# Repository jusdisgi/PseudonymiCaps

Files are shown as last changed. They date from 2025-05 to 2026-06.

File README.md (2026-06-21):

# PseudonymiCaps - PG1316 (mostly) Keycaps

Parametric, 3D-printable **keycap profiles** for low-profile mechanical keyboards — sculpted
caps you generate yourself in [OpenSCAD](https://openscad.org/) and export to STL for FDM, resin,
or CNC. Profiles are tuned for **Kailh PG1316S** and **Kailh Choc v1** switches across a range of
key spacings.

> Profiles originate with **Pseudoku** (proprietor of [Asymplex](http://asymplex.xyz/), author of
> the [DES profile](https://kbd.news/On-the-DES-keycap-profile-2229.html)), with additions by
> zzeneg and others. This repo is a slimmed-down, PG1316S-focused descendant — see
> [Why this repo](#why-this-repo).

---

## Quick start (5 minutes)

1. **Install OpenSCAD** (free, all platforms): <https://openscad.org/downloads.html>.
2. **Clone this repo** (the `libraries/` folder must sit next to the profile files).
3. **Open a profile** — e.g. `Subliminal_Contradiction_17x17.scad` — in OpenSCAD.
4. **Pick a key** near the top of the file:
   ```
   keyID = 0;   // which row/size to generate (the comment lists them)
   ```
5. Press **F5** to preview, **F6** to render, then **File → Export → Export as STL**.

That's it. Each profile file has a short **USER KNOBS** block at the top — spacing, stem type, and
which key to render — and you don't need to touch anything below it.

---

## Which file do I open?

| You want… | Open |
|---|---|
| **Subliminal Contradiction** (newest, low + sculpted), alphas | `Subliminal_Contradiction_<spacing>.scad` |
| Subliminal Contradiction thumb / mod caps (convex) | `Subliminal_Contradiction_Convex.scad` |
| **DES** (high-sculpt smooth) | `PG1316_DES_<spacing>_<variant>.scad` |
| **Chicago Stenographer** (subtle low-profile sculpt) | `PG1316_Chicago_Steno_<spacing>_<variant>.scad` |
| Convex / thumb variants of CS | `PG1316_Chicago_Steno_Convex_<spacing>_<variant>.scad` |

`<spacing>` is the key pitch: `17x17`, `18x17`, `19x19`, etc. `<variant>` is the PG1316 mount cutout:
`minZ` (lowest, no foam), `Foam05` (0.5 mm deeper for thin damping foam), or `Foam1` (1 mm deeper).
Subliminal Contradiction also ships a fully parametric master (`Subliminal_Contradiction.scad`)
where you set `unit_x`/`unit_y` yourself, plus standalone presets for **16×16, 17×17, 18×17, and
19.05×19.05**.

### Picking a spacing and stem

- **Stem / switch:** PG1316S caps also fit **Choc v1**. In the Subliminal Contradiction files set
  `stemType` in the USER KNOBS block to `"PG1316S"`, `"Choc"`, or `"MX"`.
- **Spacing:** most low-profile splits use **17×17** or **18×17**. **16×16** is tight/minimal,
  **19.05×19.05** is standard MX spacing. Cap footprint = `pitch − gap` (gap ≈ 1.6 mm by default).

---

## Subliminal Contradiction

A reconstruction of Pseudoku's **Subliminal Contradiction** — a next-gen DES that's lower and
flatter (like Chicago Steno) but as sculpted as DES, with a deeper "huggier" dish and a wide top
surface. The original ships as MX-stem STLs only; here it's rebuilt parametrically so it can be
generated for Choc / PG1316S at low profile and any spacing.

- **Alphas:** 3-row sculpt — `keyID` `1`=R2 (top, leans back), `0`=R3 (home), `2`=R4 (bottom,
  leans forward), `3`=uniform/flat, plus left-hand reach variants (`4`/`5`/`6`). Homing key =
  render `keyID 0` with `homeDot=true`. Right-hand reach = negate the row's `YSkew` (or mirror).
- **Thumbs / mods:** `Subliminal_Contradiction_Convex.scad`, sizes 1.0–2.25u + a slanted thumb.
- **Mount / foam:** every SC file takes a `pgCutout` knob — `"nofoam"` (min height), `"foam05"`,
  `"foam1"` (quieter, auto +0.5/+1.0 mm height), or `"old"` (Kailh) — using the same
  `PG1316_Negspace` cutouts as the DES/CS files. Labeled `_Foam05`/`_Foam1` presets exist for
  17×17 and 18×17; any other spacing just set the knob.
- See [`docs/SC_RECONSTRUCTION.md`](docs/SC_RECONSTRUCTION.md) for exactly how the shape was
  measured from the originals and fit — and how to verify your renders against them
  (`tools/verify_sc.py`, `tools/render_sc.sh`).

---

## PG1316 mount cutouts

The PG1316 / PG1316S switch needs an unusual internal cutout. The DES and Chicago Steno files come
in variants for four cutout shapes (the library shapes live in `libraries/`):

1. **old** — the official Kailh cutout. Works great with the switches, but hard to print accurately.
2. **nofoam** — an "EZ-Print" cutout (by Mike Holscher) designed to 3D-print more easily.
3. **Foam05** — the EZ-Print cutout, 0.5 mm deeper, leaving room for a thin sound-damping foam
   layer (caps are 0.5 mm taller to suit).
4. **Foam1** — EZ-Print, 1 mm deeper, for a thicker foam layer (more cap height again).

---

## Editing profiles / making your own

Every profile is a table of per-key rows. The big `keyParameters` and `dishParameters` arrays
define the cap body and the dish (scoop) respectively. A friendly column-by-column guide lives in
[`docs/PROFILE_PARAMETERS.md`](docs/PROFILE_PARAMETERS.md). Short version: change a number, press
F5, look at the cross-section (`crossSection=true` cuts the cap in half so you can see the walls).

The profile families, briefly:

- **DES (Distorted Ellipsoidal Saddle)** — high-sculpt, smooth row-to-row transition.
- **Chicago Stenographer (CS)** — subtly sculpted, choc-spaced, low profile; convex variant for thumbs.
- **Subliminal Contradiction** — lower/flatter than DES with a deeper dish and broad top (see above).
- **Philadelphia Minimalist** — minimal spacing (upstream, under construction).

---

## Why this repo

Pseudoku's [original repo](https://github.com/pseudoku/PseudoMakeMeKeyCapProfiles) has a long fork
history and a `.git` directory over 1.5 GB (mostly old STL exports). This is a clean, small
descendant — only the files needed to *generate* caps — focused on adapting the profiles to the
ultra-low-profile **Kailh PG1316S** switch (the 17×17 files also fit Choc; PG caps are ~0.5 mm
taller than zzeneg's ultra-low Choc DES because the PG mounting slot needs the room). STL exports
live elsewhere and are linked when available.

## License

See [LICENSE](LICENSE). Profiles derive from Pseudoku's work; please keep attribution.

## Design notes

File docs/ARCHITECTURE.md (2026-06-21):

# Repo architecture & cleanup notes

## How a profile file is organized

Each profile `.scad` has the same shape, top to bottom:

1. `use <./libraries/...>` — the sweep/skin/scad-utils helpers and `PG1316S_Negative_Space.scad`.
2. **USER KNOBS** — `keyID`, spacing (`unit_x`/`unit_y`/`gap`), `stemType`, and the `keycap(...)`
   render call with toggles. *This is the only block most users touch.*
3. **Engine parameters** — resolution + wall/stem constants.
4. **`keyParameters` / `dishParameters`** tables — one row per key (see `PROFILE_PARAMETERS.md`).
5. **Accessor functions** — name the columns (`BottomWidth`, `KeyHeight`, `XAngleSkew`, …).
   In the Subliminal Contradiction files `BottomWidth`/`BottomLength` are spacing-aware
   (`unit_x * units - gap`), so one file works at any pitch.
6. **`keycap` module** + helpers (`choc_stem`, `mx_stem`, `elliptical_rectangle`, …).

Per the repo convention, **one file per spacing** (`*_17x17`, `*_18x17`, `*_19x19`). This avoids
OpenSCAD's `use`-scope limitation: a `use`d module resolves globals like `keyParameters` at the call
site, so cap dimensions can't be cleanly overridden across files. Subliminal Contradiction keeps the
convention with standalone presets, but is *also* parametric (set `unit_x`/`unit_y` in the master).

## Current cleanup done

- Beginner `README.md` with a 5-minute quickstart and a "which file do I open" table.
- `docs/PROFILE_PARAMETERS.md` — plain-language column reference.
- `docs/SC_RECONSTRUCTION.md` — worked example (measure a target, fit parameters).
- Consistent **USER KNOBS** header + `stemType` selector across the new Subliminal Contradiction
  files, which serve as the clean exemplar for the house style.
- `tools/` — STL slicer, the numpy port of the shell math, and a render+overlay verifier.

## Proposed deeper refactor (render-gated)

The `keycap` module and pure helper functions are duplicated across ~16 files. The safe way to
de-duplicate, **verified one file at a time in OpenSCAD** (don't do it blind):

1. Move the **pure helpers** (`elliptical_rectangle`, `rounded_rectangle_profile`, `ellipse`,
   `sign_x/sign_y`) into `libraries/keycap_helpers.scad` and `use` them. These have no dependency on
   `keyParameters`, so `use` is safe. Removes the largest block of duplication with low risk.
2. Refactor the `keycap` module to take the parameter **row as an argument** instead of reading the
   global `keyParameters[keyID]`. That makes the whole engine `use`-safe and lets it live in one
   `libraries/keycap_engine.scad`, with each profile reduced to its tables + a thin call.
3. Standardize file/column naming and add the USER KNOBS header to the older DES/CS files.

Step 1 is mechanical and low-risk; steps 2–3 change the module signature and every call site, so
each converted profile should be rendered and (ideally) overlaid against a known-good STL with
`tools/verify_sc.py` before committing.

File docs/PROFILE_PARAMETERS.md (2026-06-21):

# Profile parameters — a friendly guide

Every profile file is driven by two tables: **`keyParameters`** (the cap body) and
**`dishParameters`** (the scooped top). One row per key; `keyID` selects the row. You tune a cap by
editing numbers in these rows and pressing **F5**. Turn on `crossSection=true` to slice the cap in
half and watch the walls and dish as you tweak.

Units are millimetres and degrees. Angles accumulate over the vertical sweep, so a few degrees goes
a long way.

## `keyParameters` columns

| # | Name | What it does |
|--:|---|---|
| 0 | `BotWid` / units | Cap bottom width. In Subliminal Contradiction this column is **width in units** and the footprint is computed as `unit_x * units - gap`. In the older files it's an absolute mm width. |
| 1 | `BotLen` / units | Cap bottom length (same convention as col 0, using `unit_y`). |
| 2 | `TWDif` | How much **narrower the top is than the bottom**, in width. Bigger = more taper / smaller top. Smaller = wider top surface. |
| 3 | `TLDif` | Same, for length (front-to-back). |
| 4 | `keyh` | **Cap height** (top above the seating plane). The single biggest knob for profile height. |
| 5 | `WSft` | Shifts the top sideways (X) relative to the bottom. |
| 6 | `LSft` | Shifts the top forward/back (Y). |
| 7 | `XSkew` | **Front-back tilt.** Negative leans the cap **back** (top rows), positive leans it **forward** (bottom rows). |
| 8 | `YSkew` | **Left-right tilt.** Used for inner-column "reach" keys; positive raises the right edge. |
| 9 | `ZSkew` | Yaw (rotation about vertical). Usually 0. |
| 10 | `WEx` | Width taper *exponent* — how the taper is distributed up the height (2 ≈ gentle barrel). |
| 11 | `LEx` | Length taper exponent. |
| 12 | `CapR0i` | Corner rounding at the **bottom**, axis 0. |
| 13 | `CapR0f` | Corner rounding at the **top**, axis 0. Larger = rounder top corners. |
| 14 | `CapR1i` | Corner rounding at the bottom, axis 1. |
| 15 | `CapR1f` | Corner rounding at the top, axis 1. |
| 16 | `CapREx` | Exponent controlling how rounding blends bottom→top. |
| 17 | `StemEx` | Exponent for the stem-to-top transition support. |

## `dishParameters` columns

The dish is a saddle swept from a **front** trajectory and a **back** trajectory that meet in the
middle. Most rows only need small tweaks from a working baseline.

| # | Name | What it does |
|--:|---|---|
| 0 | `FFwd1` | Front trajectory: first segment length. |
| 1 | `FFwd2` | Front trajectory: second segment length. |
| 2 | `FPit1` | Front pitch (curvature) of segment 1 — controls how the front lip rises. |
| 3 | `FPit2` | Front pitch of segment 2. |
| 4 | `DshDep` | **Dish depth** — how deep the scoop is. Bigger = "huggier". |
| 5 | `DshHDif` | How far **below the cap top** the dish sits (vertical placement of the scoop). |
| 6 | `FArcIn` | Front dish arc radius at the start (side-to-side curvature of the scoop). |
| 7 | `FArcFn` | Front dish arc radius at the end. |
| 8 | `FArcEx` | Exponent blending `FArcIn`→`FArcFn`. |
| 9–15 | `BFwd1 BFwd2 BPit1 BPit2 BArcIn BArcFn BArcEx` | Same set for the **back** half of the saddle. |

## Common edits

- **Lower the whole cap:** decrease `keyh` (col 4), or set the file's global `heightDelta` negative.
- **Wider, flatter top (more keycap surface):** decrease `TWDif`/`TLDif`.
- **Deeper scoop:** increase `DshDep`; if it pokes through the wall, also nudge `DshHDif`.
- **Change row tilt:** adjust `XSkew` (front-back). Negative = leans back, positive = leans forward.
- **Inner-column reach key:** add a few degrees of `YSkew` (negate for the opposite hand).
- **Inspect walls/dish:** set `crossSection=true` in the render call and press F5.

See [`SC_RECONSTRUCTION.md`](SC_RECONSTRUCTION.md) for a worked example: measuring a target shape
and fitting these parameters to it.

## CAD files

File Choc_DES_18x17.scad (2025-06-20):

use <./libraries/scad-utils/morphology.scad> //for cheaper minwoski
use <./libraries/scad-utils/transformations.scad>
use <./libraries/scad-utils/shapes.scad>
use <./libraries/scad-utils/trajectory.scad>
use <./libraries/scad-utils/trajectory_path.scad>
use <./libraries/sweep.scad>
use <./libraries/skin.scad>
//use <z-butt.scad>

/*DES (Distorted Elliptical Saddle) Sculpted Profile for 6x3 and corne thumb
Version 2: Eliptical Rectangle
*/

//Cheat Sheet: key KeyIDs to know
//0 Regular bottom alpha row (R4)
//1 Regular home row (R3)
//2 Regular top alpha row (R2)
//5 Regular num row (R1)
//43 Edge R4
//44 Edge R3
//45 Edge R2
//46 Edge R1
//47 Thumb
//48 Thumb
//49 Thumb

// Configure keycap to render here. You probably only want to
// do one at a time unless your computer is real fast.
keycap(
    keyID  = 1, //change profile refer to KeyParameters Struct
    Stem   = true, //tusn on shell and stems
    Dish   = true, //turn on dish cut
    visualizeDish = false, // turn on debug visual of Dish
    crossSection  = false, // center cut to check internal
    homeDot = false, //turn on homedots
    homeRing = false, //turn on homing rings
    homeBar = true, //turn on homing bar
    Legends = false
);


//Cheat Sheet: key KeyIDs to know
//0 Regular bottom alpha row (R4)
//1 Regular home row (R3)
//2 Regular top alpha row (R2)
//5 Regular num row (R1)
//43 Edge R4
//44 Edge R3
//45 Edge R2
//46 Edge R1
//47 Thumb
//48 Thumb
//49 Thumb

//Parameters
wallthickness = 1.2; // 1.5 for norm, 1.2 for cast master
topthickness  = 1.2; // 2 for norm, 1.6 for cast master
stepsize      = 60;  //resolution of Trajectory
step          = 0.5;   //resolution of ellipes
fn            = 60;  //resolution of Rounded Rectangles: 60 for output
layers        = 50;  //resolution of vertical Sweep: 50 for output
dotRadius     = 0.55;   //home dot size; default 0.55
//---Stem param
stemLayers      = 50; //resolution of stem to cap top transition
stemHeightDelta = 0.3;

heightDelta = -5.25;

keyParameters = //keyParameters[KeyID][ParameterID]
[
//  BotWid, BotLen, TWDif, TLDif, keyh, WSft, LSft  XSkew, YSkew, ZSkew, WEx, LEx, CapR0i, CapR0f, CapR1i, CapR1f, CapREx, StemEx
//Column high sculpt 3 row system
    //0~5
    [16.4,  15.4,   6.5, 	 4.5,10.55,    0,    0,     9,     0,     0,   2,   2,      1,      5,      1,    3.5,     2,       2], //0 R4 8
    [16.4,  15.4,   6.5, 	 4.5, 8.75,    0,   .5,     4,     0,     0,   2,   2,      1,      5,      1,    3.5,     2,       2], //1 R3 Home
    [16.4,  15.4,   6.5, 	 4.5, 9.75,    0,    0,   -13,     0,     0,   2,   2,      1,      5,      1,    3.5,     2,       2], //2 R2
    [16.4,  15.4,   6.5, 	 4.5, 8.75,    0,    0,     4,     0,     0,   2,   2,      1,      5,      1,    3.5,     2,       2], //3 R3 deepdish
    [16.4,  15.4,   6.5, 	 4.5, 11.5,    0,    0,    -3,     0,     0,   2,   2,      1,      5,      1,    3.5,     2,       2], //4 R5 mod
    [16.4,  15.4,   6.5, 	 4.5, 15.0,    0,  -.5,    20,     0,     0,   2,   2,      1,      5,      1,    3.5,     2,       2], //5 R1 num

    //1.25u 6~9
    [20.6,  15.4,   6.5, 	 4.5, 11.5,    0,    0,    -3,     0,     0,   2,   2,      1,      5,      1,    3.5,     2,       2], //6 R5
    [20.6,  15.4,   6.5, 	 4.5,10.55,    0,    0,     9,     0,     0,   2,   2,      1,      5,      1,    3.5,     2,       2], //7 R4  // neuron 3 deg
    [20.6,  15.4,   6.5, 	 4.5, 8.75,    0,   .5,     4,    -0,     0,   2,   2,      1,      5,      1,    3.5,     2,       2], //8 R3 Home
    [20.6,  15.4,   6.5, 	 4.5, 9.75,    0,    0,   -13,     0,     0,   2,   2,      1,      5,      1,    3.5,     2,       2], //9 R2
    //1.5u 10~13
    [2,  15.4,   6.5, 	 4.5, 11.5,    0,    0,    -3,     0,     0,   2,   2,      1,      5,      1,    3.5,     2,       2], //10 R5
    [24.9,  15.4,   6.5, 	 4.5,10.55,    0,    0,     9,     0,     0,   2,   2,      1,      5,      1,    3.5,     2,       2], //11 R4
    [24.9,  15.4,   6.5, 	 4.5, 8.75,    0,   .5,     4,     0,     0,   2,   2,      1,      5,      1,    3.5,     2,       2], //12 R3 Home
    [24.9,  15.4,   6.5, 	 4.5, 9.75,    0,    0,   -13,     0,     0,   2,   2,      1,      5,      1,    3.5,     2,       2], //13 R2
    //1.75u 14~17
    [29.2,  15.4,   6.5, 	 4.5, 11.5,    0,    0,    -3,     0,     0,   2,   2,      1,      5,      1,    3.5,     2,       2], //14 R5
    [29.2,  15.4,   6.5, 	 4.5,10.55,    0,    0,     9,    -0,     0,   2,   2,      1,      5,      1,    3.5,     2,       2], //15 R4
    [29.2,  15.4,   6.5, 	 4.5, 8.75,    0,   .5,     4,     0,     0,   2,   2,      1,      5,      1,    3.5,     2,       2], //16 R3 Home
    [29.2,  15.4,   6.5, 	 4.5, 9.75,    0,    0,   -13,     0,     0,   2,   2,      1,      5,      1,    3.5,     2,       2], //17 R2
    //2.0u  18~22
    [33.4,  15.4,   6.5, 	 4.5, 11.5,    0,    0,    -3,     0,     0,   2,   2,      1,      5,      1,    3.5,     2,       2], //18 R5
    [33.4,  15.4,   6.5, 	 4.5,10.55,    0,    0,     9,     0,     0,   2,   2,      1,      5,      1,    3.5,     2,       2], //19 R4
    [33.4,  15.4,   6.5, 	 4.5, 8.75,    0,   .5,     4,     0,     0,   2,   2,      1,      5,      1,    3.5,     2,       2], //20 R3 Home
    [33.4,  15.4,   6.5, 	 4.5, 9.75,    0,    0,   -13,     0,     0,   2,   2,      1,      5,      1,    3.5,     2,       2], //21 R2
    [33.4,  15.4,   6.5, 	 4.5,   15,    0,  -.5,    20,     0,     0,   2,   2,      1,      5,      1,    3.5,     2,       2], //22 R1
    //2.25u 23~26
    [37.7,  15.4,   6.5, 	 4.5, 11.5,    0,    0,    -3,    -0,     0,   2,   2,      1,      5,      1,    3.5,     2,       2], //23 R5
    [37.7,  15.4,   6.5, 	 4.5,10.55,    0,    0,     9,     0,     0,   2,   2,      1,      5,      1,    3.5,     2,       2], //24 R4
    [37.7,  15.4,   6.5, 	 4.5, 8.75,    0,   .5,     4,     0,     0,   2,   2,      1,      5,      1,    3.5,     2,       2], //25 R3 Home
    [37.7,  15.4,   6.5, 	 4.5, 9.75,    0,    0,   -13,     0,     0,   2,   2,      1,      5,      1,    3.5,     2,       2], //26 R2
    //2.50u 27~30
    [41.9,  15.4,   6.5, 	 4.5, 11.5,    0,    0,    -3,     0,     0,   2,   2,      1,      5,      1,    3.5,     2,       2], //27 R5  // neuron 2deg height to 10.5
    [41.9,  15.4,   6.5, 	 4.5,10.55,    0,    0,     9,     0,     0,   2,   2,      1,      5,      1,    3.5,     2,       2], //28 R4
    [41.9,  15.4,   6.5, 	 4.5, 8.75,    0,   .5,     4,     0,     0,   2,   2,      1,      5,      1,    3.5,     2,       2], //29 R3 Home
    [41.9,  15.4,   6.5, 	 4.5, 9.75,    0,    0,   -13,     0,     0,   2,   2,      1,      5,      1,    3.5,     2,       2], //30 R2
    //2.75u 31~34
    [46.2,  15.4,   6.5, 	 4.5, 11.5,    0,    0,    -3,     0,     0,   2,   2,      1,      5,      1,    3.5,     2,       2], //31 R5
    [46.2,  15.4,   6.5, 	 4.5,10.55,    0,    0,     9,     0,     0,   2,   2,      1,      5,      1,    3.5,     2,       2], //32 R4
    [46.2,  15.4,   6.5, 	 4.5, 8.75,    0,   .5,    -4,     0,     0,   2,   2,      1,      5,      1,    3.5,     2,       2], //33 R3 Home
    [46.2,  15.4,   6.5, 	 4.5, 9.75,    0,    0,   -13,     0,     0,   2,   2,      1,      5,      1,    3.5,     2,       2], //34 R2
    //3.00u 34~37
    [50.4,  15.4,   6.5, 	 4.5, 11.5,    0,    0,    -3,    -0,     0,   2,   2,      1,      5,      1,    3.5,     2,       2], //35 R5
    [50.4,  15.4,   6.5, 	 4.5,10.55,    0,    0,     9,     0,     0,   2,   2,      1,      5,      1,    3.5,     2,       2], //36 R4
    [50.4,  15.4,   6.5, 	 4.5, 8.75,    0,   .5,     4,     0,     0,   2,   2,      1,      5,      1,    3.5,     2,       2], //37 R3 Home
    [50.4,  15.4,   6.5, 	 4.5, 9.75,    0,    0,   -13,     0,     0,   2,   2,      1,      5,      1,    3.5,     2,       2], //38 R2
    //6.25u 39
    [105.7,  15.4,   6.5, 	 4.5, 11.5,    0,    0,    -3,    -0,     0,   2,   2,      1,      5,      1,    3.5,     2,       2], //39 R5
    //7.00u 40
    [118.4,  15.4,   6.5, 	 4.5, 11.5,    0,    0,    -3,    -0,     0,   2,   2,      1,      5,      1,    3.5,     2,       2], //40 R5
    //num pad vert  2u 41
    [16.4,  33.4,   6.5, 	 6.5,10.00,    0,    0,    -5,     0,     0,   2,   2,      1,      6,      1,    3.5,     2,       2], //41 R4
    [16.4,  33.4,   6.5, 	 6.5,10.55,    0,    0,     9,     0,     0,   2,   2,      1,      5,      1,    3.5,     2,       2], //42 R4
    //edge 43-46
    [16.4,  15.4,   6.5, 	 4.5, 11.8,    0,    0,     9,    15,     0,   2,   2,      1,      5,      1,    3.5,     2,       2], //43 R4
    [16.4,  15.4,   6.5, 	 4.5,   10,    0,   .5,     4,    15,     0,   2,   2,      1,      5,      1,    3.5,     2,       2], //44 R3
    [16.4,  15.4,   6.5, 	 4.5,   11,    0,    0,   -13,    15,     0,   2,   2,      1,      5,      1,    3.5,     2,       2], //45 R2
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

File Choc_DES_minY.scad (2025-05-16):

use <./libraries/scad-utils/morphology.scad> //for cheaper minwoski
use <./libraries/scad-utils/transformations.scad>
use <./libraries/scad-utils/shapes.scad>
use <./libraries/scad-utils/trajectory.scad>
use <./libraries/scad-utils/trajectory_path.scad>
use <./libraries/sweep.scad>
use <./libraries/skin.scad>
//use <z-butt.scad>

/*DES (Distorted Elliptical Saddle) Sculpted Profile for 6x3 and corne thumb
Version 2: Eliptical Rectangle
*/

//Cheat Sheet: key KeyIDs to know
//0 Regular bottom alpha row (R4)
//1 Regular home row (R3)
//2 Regular top alpha row (R2)
//5 Regular num row (R1)
//43 Edge R4
//44 Edge R3
//45 Edge R2
//46 Edge R1
//47 Thumb
//48 Thumb
//49 Thumb

// Configure keycap to render here. You probably only want to
// do one at a time unless your computer is real fast.
keycap(
    keyID  = 1, //change profile refer to KeyParameters Struct
    Stem   = true, //tusn on shell and stems
    Dish   = true, //turn on dish cut
    visualizeDish = false, // turn on debug visual of Dish
    crossSection  = false, // center cut to check internal
    homeDot = false, //turn on homedots
    homeRing = false, //turn on homing rings
    Legends = false
);

//Parameters
wallthickness = 1.2; // 1.5 for norm, 1.2 for cast master
topthickness  = 1.2; // 2 for norm, 1.6 for cast master
stepsize      = 60;  //resolution of Trajectory
step          = 0.5;   //resolution of ellipes
fn            = 60;  //resolution of Rounded Rectangles: 60 for output
layers        = 50;  //resolution of vertical Sweep: 50 for output
dotRadius     = 0.55;   //home dot size; default 0.55
//---Stem param
stemLayers      = 50; //resolution of stem to cap top transition
stemHeightDelta = 0.3;

heightDelta = -5.25;

keyParameters = //keyParameters[KeyID][ParameterID]
[
//  BotWid, BotLen, TWDif, TLDif, keyh, WSft, LSft  XSkew, YSkew, ZSkew, WEx, LEx, CapR0i, CapR0f, CapR1i, CapR1f, CapREx, StemEx
//Column high sculpt 3 row system
    //0~5
    [17.16,  14.36,   6.5, 	 4.5,10.55,    0,    0,     9,     0,     0,   2,   2,      1,      5,      1,    3.5,     2,       2], //0 R4 8
    [17.16,  14.36,   6.5, 	 4.5, 8.75,    0,   .5,     4,     0,     0,   2,   2,      1,      5,      1,    3.5,     2,       2], //1 R3 Home
    [17.16,  14.36,   6.5, 	 4.5, 9.75,    0,    0,   -13,     0,     0,   2,   2,      1,      5,      1,    3.5,     2,       2], //2 R2
    [17.16,  14.36,   6.5, 	 4.5, 8.75,    0,    0,     4,     0,     0,   2,   2,      1,      5,      1,    3.5,     2,       2], //3 R3 deepdish
    [17.16,  14.36,   6.5, 	 4.5, 11.5,    0,    0,    -3,     0,     0,   2,   2,      1,      5,      1,    3.5,     2,       2], //4 R5 mod
    [17.16,  14.36,   6.5, 	 4.5, 15.0,    0,  -.5,    20,     0,     0,   2,   2,      1,      5,      1,    3.5,     2,       2], //5 R1 num

    //1.25u 6~9
    [21.86,  14.36,   6.5, 	 4.5, 11.5,    0,    0,    -3,     0,     0,   2,   2,      1,      5,      1,    3.5,     2,       2], //6 R5
    [21.86,  14.36,   6.5, 	 4.5,10.55,    0,    0,     9,     0,     0,   2,   2,      1,      5,      1,    3.5,     2,       2], //7 R4  // neuron 3 deg
    [21.86,  14.36,   6.5, 	 4.5, 8.75,    0,   .5,     4,    -0,     0,   2,   2,      1,      5,      1,    3.5,     2,       2], //8 R3 Home
    [21.86,  14.36,   6.5, 	 4.5, 9.75,    0,    0,   -13,     0,     0,   2,   2,      1,      5,      1,    3.5,     2,       2], //9 R2
    //1.5u 10~13
    [26.66,  14.36,   6.5, 	 4.5, 11.5,    0,    0,    -3,     0,     0,   2,   2,      1,      5,      1,    3.5,     2,       2], //10 R5
    [26.66,  14.36,   6.5, 	 4.5,10.55,    0,    0,     9,     0,     0,   2,   2,      1,      5,      1,    3.5,     2,       2], //11 R4
    [26.66,  14.36,   6.5, 	 4.5, 8.75,    0,   .5,     4,     0,     0,   2,   2,      1,      5,      1,    3.5,     2,       2], //12 R3 Home
    [26.66,  14.36,   6.5, 	 4.5, 9.75,    0,    0,   -13,     0,     0,   2,   2,      1,      5,      1,    3.5,     2,       2], //13 R2
    //1.75u 14~17
    [31.40,  14.36,   6.5, 	 4.5, 11.5,    0,    0,    -3,     0,     0,   2,   2,      1,      5,      1,    3.5,     2,       2], //14 R5
    [31.40,  14.36,   6.5, 	 4.5,10.55,    0,    0,     9,    -0,     0,   2,   2,      1,      5,      1,    3.5,     2,       2], //15 R4
    [31.40,  14.36,   6.5, 	 4.5, 8.75,    0,   .5,     4,     0,     0,   2,   2,      1,      5,      1,    3.5,     2,       2], //16 R3 Home
    [31.40,  14.36,   6.5, 	 4.5, 9.75,    0,    0,   -13,     0,     0,   2,   2,      1,      5,      1,    3.5,     2,       2], //17 R2
    //2.0u  18~22
    [36.26,  14.36,   6.5, 	 4.5, 11.5,    0,    0,    -3,     0,     0,   2,   2,      1,      5,      1,    3.5,     2,       2], //18 R5
    [36.26,  14.36,   6.5, 	 4.5,10.55,    0,    0,     9,     0,     0,   2,   2,      1,      5,      1,    3.5,     2,       2], //19 R4
    [36.26,  14.36,   6.5, 	 4.5, 8.75,    0,   .5,     4,     0,     0,   2,   2,      1,      5,      1,    3.5,     2,       2], //20 R3 Home
    [36.26,  14.36,   6.5, 	 4.5, 9.75,    0,    0,   -13,     0,     0,   2,   2,      1,      5,      1,    3.5,     2,       2], //21 R2
    [36.26,  14.36,   6.5, 	 4.5,   15,    0,  -.5,    20,     0,     0,   2,   2,      1,      5,      1,    3.5,     2,       2], //22 R1
    //2.25u 23~26
    [40.96,  14.36,   6.5, 	 4.5, 11.5,    0,    0,    -3,    -0,     0,   2,   2,      1,      5,      1,    3.5,     2,       2], //23 R5
    [40.96,  14.36,   6.5, 	 4.5,10.55,    0,    0,     9,     0,     0,   2,   2,      1,      5,      1,    3.5,     2,       2], //24 R4
    [40.96,  14.36,   6.5, 	 4.5, 8.75,    0,   .5,     4,     0,     0,   2,   2,      1,      5,      1,    3.5,     2,       2], //25 R3 Home
    [40.96,  14.36,   6.5, 	 4.5, 9.75,    0,    0,   -13,     0,     0,   2,   2,      1,      5,      1,    3.5,     2,       2], //26 R2
    //2.50u 27~30
    [45.66,  14.36,   6.5, 	 4.5, 11.5,    0,    0,    -3,     0,     0,   2,   2,      1,      5,      1,    3.5,     2,       2], //27 R5  // neuron 2deg height to 10.5
    [45.66,  14.36,   6.5, 	 4.5,10.55,    0,    0,     9,     0,     0,   2,   2,      1,      5,      1,    3.5,     2,       2], //28 R4
    [45.66,  14.36,   6.5, 	 4.5, 8.75,    0,   .5,     4,     0,     0,   2,   2,      1,      5,      1,    3.5,     2,       2], //29 R3 Home
    [45.66,  14.36,   6.5, 	 4.5, 9.75,    0,    0,   -13,     0,     0,   2,   2,      1,      5,      1,    3.5,     2,       2], //30 R2
    //2.75u 31~34
    [50.66,  14.36,   6.5, 	 4.5, 11.5,    0,    0,    -3,     0,     0,   2,   2,      1,      5,      1,    3.5,     2,       2], //31 R5
    [50.66,  14.36,   6.5, 	 4.5,10.55,    0,    0,     9,     0,     0,   2,   2,      1,      5,      1,    3.5,     2,       2], //32 R4
    [50.66,  14.36,   6.5, 	 4.5, 8.75,    0,   .5,    -4,     0,     0,   2,   2,      1,      5,      1,    3.5,     2,       2], //33 R3 Home
    [50.66,  14.36,   6.5, 	 4.5, 9.75,    0,    0,   -13,     0,     0,   2,   2,      1,      5,      1,    3.5,     2,       2], //34 R2
    //3.00u 34~37
    [55.36,  14.36,   6.5, 	 4.5, 11.5,    0,    0,    -3,    -0,     0,   2,   2,      1,      5,      1,    3.5,     2,       2], //35 R5
    [55.36,  14.36,   6.5, 	 4.5,10.55,    0,    0,     9,     0,     0,   2,   2,      1,      5,      1,    3.5,     2,       2], //36 R4
    [55.36,  14.36,   6.5, 	 4.5, 8.75,    0,   .5,     4,     0,     0,   2,   2,      1,      5,      1,    3.5,     2,       2], //37 R3 Home
    [55.36,  14.36,   6.5, 	 4.5, 9.75,    0,    0,   -13,     0,     0,   2,   2,      1,      5,      1,    3.5,     2,       2], //38 R2
    //6.25u 39
    [117.1,  14.36,   6.5, 	 4.5, 11.5,    0,    0,    -3,    -0,     0,   2,   2,      1,      5,      1,    3.5,     2,       2], //39 R5
    //7.00u 40
    [131.4,  14.36,   6.5, 	 4.5, 11.5,    0,    0,    -3,    -0,     0,   2,   2,      1,      5,      1,    3.5,     2,       2], //40 R5
    //num pad vert  2u 41
    [17.16,  36.26,   6.5, 	 6.5,10.00,    0,    0,    -5,     0,     0,   2,   2,      1,      6,      1,    3.5,     2,       2], //41 R4
    [17.16,  36.26,   6.5, 	 6.5,10.55,    0,    0,     9,     0,     0,   2,   2,      1,      5,      1,    3.5,     2,       2], //42 R4
    //edge 43-46
    [17.16,  14.36,   6.5, 	 4.5, 11.8,    0,    0,     9,    15,     0,   2,   2,      1,      5,      1,    3.5,     2,       2], //43 R4
    [17.16,  14.36,   6.5, 	 4.5,   10,    0,   .5,     4,    15,     0,   2,   2,      1,      5,      1,    3.5,     2,       2], //44 R3
    [17.16,  14.36,   6.5, 	 4.5,   11,    0,    0,   -13,    15,     0,   2,   2,      1,      5,      1,    3.5,     2,       2], //45 R2
    [17.16,  14.36,   6.5, 	 4.5, 15.3,    0,  -.5,   -20,    15,     0,   2,   2,      1,      5,      1,    3.5,     2,       2], //46 R1 num
    //thumbs 47-49
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

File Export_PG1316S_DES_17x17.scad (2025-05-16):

use <PG1316S_DES_17x17.scad>

spacing = 17.00;
vertical_spacing = 17.00;
spru_radius = 0.8;
width=1;

spru_n = 3;
start_row = 2; end_row = 4;

union() {
    for (i = [start_row : end_row]) {
        translate([0, -vertical_spacing * (i - start_row), 0]) des_spru(row=i, width=width, dot=false, edge=false);

        if (i != end_row) {
            translate([5, -vertical_spacing * (i - start_row) - 5, -0.8 * spru_radius])
            rotate([90, 0, 0])
            cylinder(h = 6, r = spru_radius, $fn=20);
        }
    }
}

//union() {
//    translate([0, -19 *  0, 0])  des_spru(row=1);
//    translate([0, -19 *  1, 0])  des_spru(row=2);
//    translate([0, -19 *  2, 0])  des_spru(row=3);
//    translate([0, -19 *  3, 0])  des_spru(row=4);
//    translate([0, -19 *  4, 0])  des_spru(row=5);
//
//    translate([0, -19 *  6, 0])  des_spru(row=2, width=1.25);
//  translate([0, -19 *  7, 0])  des_spru(row=3, width=1.25);
//  translate([0, -19 *  8, 0])  des_spru(row=4, width=1.25);
//  translate([0, -19 *  9, 0])  des_spru(row=5, width=1.25);
//
//  translate([0, -19 * 11, 0])  des_spru(row=2, width=1.5);
//  translate([0, -19 * 12, 0])  des_spru(row=3, width=1.5);
//  translate([0, -19 * 13, 0])  des_spru(row=4, width=1.5);
//    translate([0, -19 * 14, 0])  des_spru(row=5, width=1.5);
//
//  translate([0, -19 * 16, 0])  des_spru(row=2, width=1.75);
//  translate([0, -19 * 17, 0])  des_spru(row=3, width=1.75);
//  translate([0, -19 * 18, 0])  des_spru(row=4, width=1.75);
//  translate([0, -19 * 19, 0])  des_spru(row=5, width=1.75);

//  translate([0, -19 * 21, 0])  des_spru(row=5, width=2);
//  translate([0, -19 * 22, 0])  des_spru(row=5, width=2.25);
//  translate([0, -19 * 23, 0])  des_spru(row=5, width=2.75);

//    translate([0, -19 * 25, 0])  des_spru(row=3, dot=true);
//    translate([0, -19 * 0, 0])  des_spru(row=3, ring=true);
//    translate([0, -19 * 26, 0])  des_spru(row=3, deepdish=true);
//    translate([0, -19 * 27, 0])  des_spru(row=3, deepdish=false);
//}

module des_spru(row, dot=false, deepdish=false, n=spru_n, width=1, radius=spru_radius, ring=false, edge=false) {
    echo ("Row", row, "width", width);
    union() {
        for (i = [0 : n - 1]){
            translate([i * spacing * width, 0, 0])
            mirror([0,0,0])
            des_keycap(row=row, width=width, dot=dot, deepdish=deepdish, ring=ring, edge=edge);

            if (edge) {
                translate([(i + 1) * spacing * width, 0, 0])
                mirror([1,0,0])
                des_keycap(row=row, width=width, dot=dot, deepdish=deepdish, ring=ring, edge=edge);
            }
        }

        if (n > 1 || edge) {
            for (i = [0 : max(0, n - 2)]){
                translate([i * width * spacing + spacing / 2 - 3, 5, -0.8 * spru_radius])
                rotate([0, 90, 0])
                cylinder(h = 6, r = spru_radius, $fn=20);
            }
        }
    }
}

module des_keycap(row, width=1, dot=false, deepdish=false, ring=false, edge=false) {
    if      (row == 1 && edge) {des_standard(46);}
    else if (row == 1) {rotate([0, 0, 180]) des_standard(5);}

    else if (row == 2 && edge) {des_standard(45);}
    else if (row == 2 && width == 1   ) {des_standard(2);}
    else if (row == 2 && width == 1.25) {des_standard(9);}
    else if (row == 2 && width == 1.5 ) {des_standard(13);}
    else if (row == 2 && width == 1.75) {des_standard(17);}

    else if (row == 3 && edge) {des_standard(44);}
    else if (row == 3 && width == 1 && !deepdish) {des_standard(1, dot=dot, ring=ring);}
    else if (row == 3 && deepdish)      {des_standard(3);}
    else if (row == 3 && width == 1.25) {des_standard(8);}
    else if (row == 3 && width == 1.5 ) {des_standard(12);}
    else if (row == 3 && width == 1.75) {des_standard(16);}

    else if (row == 4 && edge) {des_standard(43);}
    else if (row == 4 && width == 1   ) {des_standard(0);}
    else if (row == 4 && width == 1.25) {des_standard(7);}
    else if (row == 4 && width == 1.5 ) {des_standard(11);}
    else if (row == 4 && width == 1.75) {des_standard(15);}

    else if (row == 5 && width == 1   ) {des_standard(4);}
    else if (row == 5 && width == 1.25) {des_standard(6);}
    else if (row == 5 && width == 1.5 ) {des_standard(10);}
    else if (row == 5 && width == 1.75) {des_standard(14);}
    else if (row == 5 && width == 2   ) {des_standard(18);}
    else if (row == 5 && width == 2.25) {des_standard(23);}
    else if (row == 5 && width == 2.75) {des_standard(31);}
}

module des_standard(keyID, dot=false, ring=false) {
    echo("keyID", keyID)
    keycap(
        keyID  = keyID, //change profile refer to KeyParameters Struct
        Stem   = false, //turn on shell and stems
        PG1316S = true, //turn on mounting slot
        crossSection = false,
        homeDot = dot, //turn on homedots
        homeRing = ring
    );
}

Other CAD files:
PG1316_Chicago_Steno_17x17_Foam05.scad
PG1316S_Chicago_Steno.scad
PG1316S_Chicago_Steno_17x17.scad
PG1316S_Chicago_Steno_18x17.scad
PG1316S_Chicago_Steno_19x19.scad
PG1316S_Chicago_Steno_Convex.scad
PG1316S_Chicago_Steno_Convex_17x17.scad
PG1316S_Chicago_Steno_Convex_18x17.scad
PG1316S_Chicago_Steno_Convex_19x19.scad
PG1316S_Chicago_Steno_Thumb_18x17.scad
PG1316S_Chicago_Steno_Thumb_19x19.scad
PG1316S_DES_17x17.scad
PG1316S_DES_17x17_Foam05.scad
PG1316S_DES_17x17_Foam1.scad
PG1316S_DES_18x17.scad
PG1316S_DES_18x17_Foam05.scad
PG1316S_DES_18x17_Foam1.scad
PG1316S_DES_19x19.scad
PG1316S_DES_19x19_Foam05.scad
PG1316S_DES_19x19_Foam1.scad
PG1316S_Negative_Space.scad
PG1316_Chicago_Steno_17x17_Foam1.scad
PG1316_Chicago_Steno_17x17_minZ.scad
PG1316_Chicago_Steno_18x17_Foam05.scad
PG1316_Chicago_Steno_18x17_Foam1.scad
PG1316_Chicago_Steno_18x17_minZ.scad
PG1316_Chicago_Steno_19x19_Foam05.scad
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

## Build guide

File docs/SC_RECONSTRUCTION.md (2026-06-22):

# Subliminal Contradiction — reconstruction notes

Pseudoku released **Subliminal Contradiction (SC)** as MX-stem / MX-spaced **STL meshes only**
(no parametric source; "Choc stem variants" is an open to-do in the original repo). To make SC
usable on Choc / Kailh PG1316S boards at low profile, the shape was **reconstructed
parametrically** in this repo's engine rather than mesh-grafted, so the result is a clean,
manifold, fully parametric cap suitable for FDM, resin, and CNC.

This document records how the parameters were derived so the fit is reproducible and tunable.

## Source geometry (measured from the original STLs)

The original STLs were parsed and sliced with `tools/sc_slice.py` (pure-numpy binary-STL reader +
plane sectioner). All caps share an **18.06 × 18.06 mm** 1u footprint (MX), convex sizes grow
4.76 mm/u. The seating plane sits at **z ≈ 0**; the skirt extends to z ≈ −1.0.

Per-row top-surface measurements (z in mm above seating plane; −Y = front):

| Cap | front rim | back rim | front-back tilt | dish min | side rim | side dish depth |
|---|---:|---:|---:|---:|---:|---:|
| R2 (top) | 3.44 | 5.95 |  **+2.51** (back high) | 2.67 | 5.40 | 1.95 |
| R3 (home)| 4.27 | 3.81 |  −0.46 (near flat) | 2.91 | 5.06 | 1.91 |
| R4 (bot) | 5.72 | 4.30 |  **−1.42** (front high) | 3.88 | 6.11 | 1.79 |
| Uniform  | 4.22 | 4.22 | 0.00 (flat) | 3.15 | 5.06 | 1.91 |
| Convex | ~5.3 center (domed) | — | — | — | — | — |
| R2 reach | 3.94 | 6.46 |  +2.52 | 3.19 |  5.11 / 6.33 (L/R) | lateral lean |
| R3 reach | 4.78 | 4.32 |  −0.45 | 3.53 |  4.92 / 5.88 | lateral lean |
| R4 reach | 6.24 | 4.80 |  −1.44 | 4.39 |  6.21 / 6.83 | lateral lean |

This matches the published spec (max height ~6.5 mm, dish minima ~3.2 mm). Key shape signatures:
a 3-row sculpt (R2 leans back, R3 ~flat, R4 leans forward), a **broad top surface** (little
taper), a **side-to-side saddle ~1.9 mm deep**, and "Left Reachy" inner-column variants that add a
**lateral lean** (right rim higher than left) on top of the row tilt.

## Fitting to the engine

Rim heights and tilts are **edge** features, so they're unaffected by the dish cut. The engine's
outer-shell math (`elliptical_rectangle` + `CapTransform/CapTranslation/CapRotation`) was ported to
numpy (`tools/sc_shell_model.py`) to predict front/back/left/right rim heights for a given
parameter row, and `keyh`, `XSkew`, `YSkew` were fit (zero yaw) to the measured rims:

| Row | keyh | XSkew | YSkew | fit RMS (mm) |
|---|-----:|---:|---:|---:|
| R3 home | 4.77 |  +2.1 | 0.0 | 0.51 |
| R2 top | 5.29 | −11.8 | 0.0 | 0.35 |
| R4 bottom  | 5.83 |  +6.7 | 0.0 | 0.55 |
| R3 uniform | 4.86 | 0.0 | 0.0 | 0.42 |
| R2 reach | 5.71 | −11.7 |  +6.9 | 0.27 |
| R3 reach | 5.20 |  +2.5 |  +5.3 | 0.44 |
| R4 reach | 6.30 |  +6.7 |  +3.3 | 0.51 |

Sign convention (confirmed against this engine): **negative XSkew leans the cap back**, positive
leans it forward; positive YSkew raises the right rim (left-hand inner reach).

The residual (~0.3–0.5 mm) is almost entirely SC's **side rims sitting higher** than the DES default
roundness/taper predicts — i.e. SC's "wider top surface area." This is captured by reducing the top
taper (`TWDif 6.5 → 5.5`, `TLDif 4.5 → 4.0`); final side-rim fit is a render-loop tuning step.

## Dish

The saddle dish is **not** fully re-derived analytically (it's a skinned-ellipse sweep). Instead the
known-good **DES dish baseline** is mapped per row (R2/R3/R4), which already lands in SC's measured
dish-minima band (~2.9–3.9 mm). SC's "deeper, huggier dish" is a small `DishDepth`/`DishHeightDif`
increase to verify against the originals — see verification below.

## Minimum height

The PG1316S mount slot (`pg1316s_negspace`) is only **1.5 mm tall** (z 0→1.5), so minimum cap height
is limited by the **dish**, not the mount. SC's native heights (R3 home top 4.27 mm, dish min ~2.9)
already clear the mount with margin, so the reconstruction preserves SC's true low profile. The
global `heightDelta` (0 by default) raises/lowers the whole set if you want to trade dish depth for
even less height.

## Verification (run on a machine with OpenSCAD)

1. `bash tools/render_sc.sh` renders each preset/row to STL via OpenSCAD CLI.
2. `python3 tools/verify_sc.py <rendered.stl> "<original SC STL>"` slices both and overlays
   sagittal + transverse cross-sections, reporting max/RMS deviation of the top surface.
3. The **19.05 MX-stem validation** preset (`Subliminal_Contradiction_19.05_MXstem_validation.scad`,
   gap 0.99 → 18.06 mm footprint) is built specifically to overlay against Pseudoku's original
   STLs and confirm the reconstructed sculpt matches before trusting the Choc/PG variants.

## Tuning log & open issues (status as of last session)

**Workflow reminder:** tune the **master** (`Subliminal_Contradiction.scad`), then run
`python3 tools/make_presets.py` to push the change into every preset (including the validation cap).
Render the **validation cap** (keyID 0) and compare to `STL/1u Row 3.stl` — they share the 18.06 mm
footprint, so the overlay lines up without rescaling. (Gotcha: editing the master alone does nothing
to what you render if you render a preset — always re-run make_presets first.)

**Current tuned parameters** (in the master):
- `heightDelta = 0.5` (rim lift to meet original SC rim height)
- dish `DishDepth = 7`, `DishHeightDif = 1.8`
- dish arcs `FArcIn/BArcIn ≈ 9.2–9.5`, `FArcFn/BArcFn ≈ 18–19`
- body taper `TWDif = 6.5`, `TLDif = 4.5` (DES-proven; a narrower taper widened the top but
  starved the dish at the corners)

**Best match so far** (validation keyID 0 = R3 home vs `1u Row 3.stl`):
- Sagittal (front-back): RMS **0.235 mm**, max **0.661 mm**
- Transverse (left-right): RMS **0.452 mm**, max **0.893 mm**

The central sculpt now tracks the original closely; the deeper dish fixed the earlier shallow-scoop
gap (sagittal RMS roughly halved from 0.52 → 0.24).

**Open issue — corner flat spots.** At the two raised saddle corners, a patch of undished cap top
remains (visible as flat triangles in the render). Deepening the dish made it worse: a deeper scoop
of the same width is narrower near the top rim, so it stops short of the corners, and the higher
rims expose more shoulder. Directions to try next (render-loop, one at a time):
1. **Widen the dish reach** — push `FArcFn`/`BArcFn` further (18 → 22+) and/or extend the dish
   trajectory with `FFwd1/FFwd2` and `BFwd1/BFwd2` so the scoop spans the full top to the corners.
2. **Sharpen the top corners** — reduce `CapR0f`/`CapR1f` (top corner rounding, currently 5 / 3.5)
   so there's less rounded shoulder that can't be dished.
3. Re-check `crossSection = true` after each so the widened/deeper dish doesn't thin the side walls.

Only keyID 0 (R3 home) has been overlay-verified. R2/R4 and the reach/convex caps still need the
same render-and-compare pass (`1u Row 2.stl`, `1u Row 4.stl`, the Convex STLs) once the dish is dialed.

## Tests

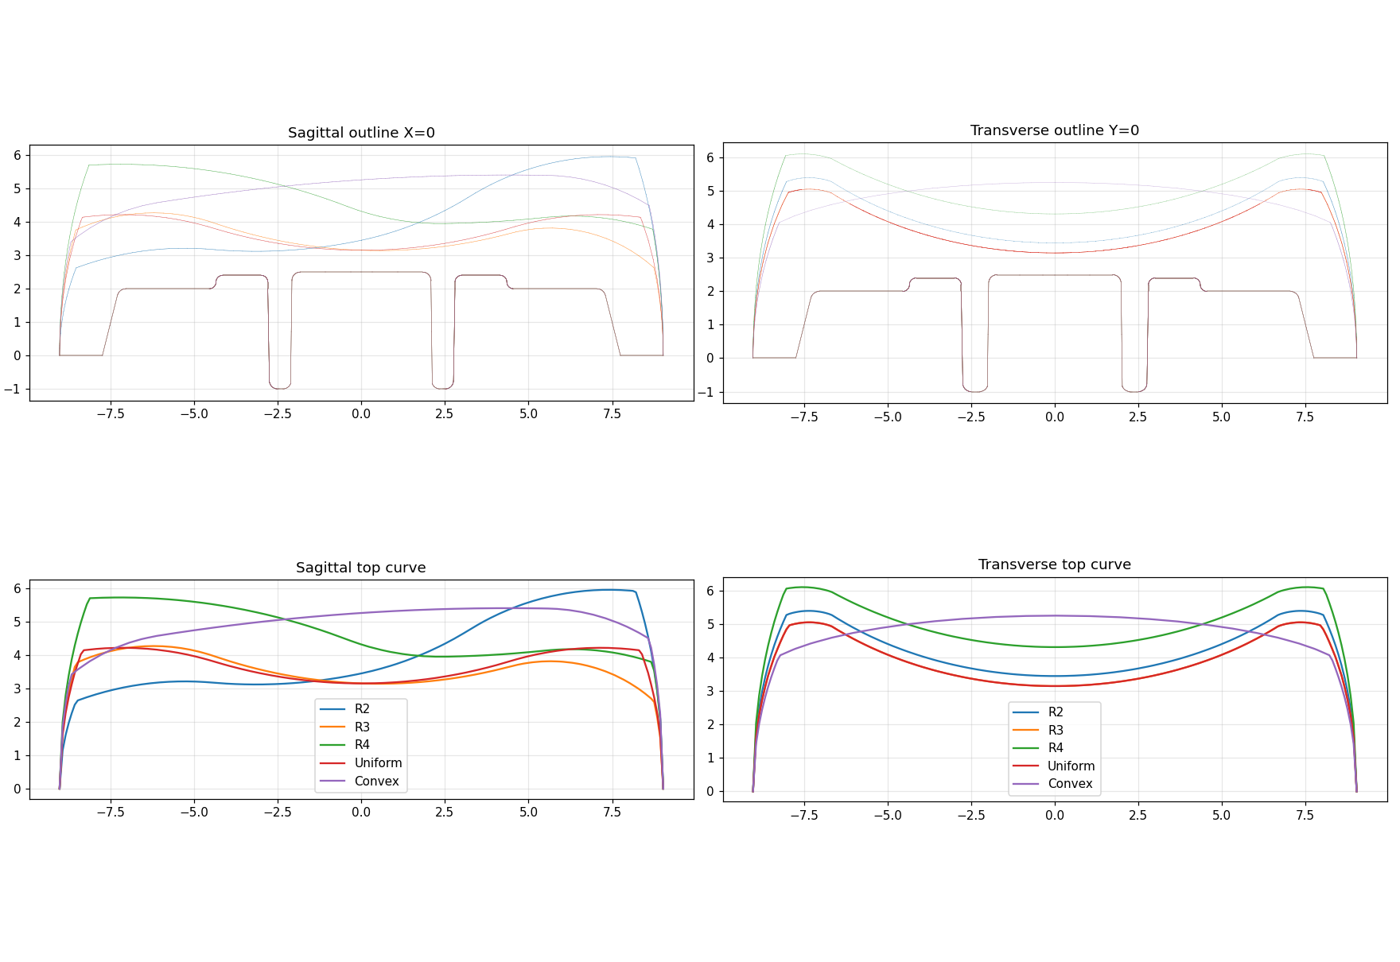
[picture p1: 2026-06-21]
docs/SC_measured_sections.png

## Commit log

2025-05-16 Initial commit. See readme for information on code lineage.
    [PG1316S_DES_17x17.scad, PG1316S_Negative_Space.scad]
2025-05-16 Make the negative space module into a library.
    [PG1316S_DES_17x17.scad]
2025-05-16 Add Choc v1 DES variants for standard spacing and min-Y spacing.
    [Choc_DES_18x17.scad, Choc_DES_minY.scad]
2025-05-16 Add export script for PG1316S DES.
    [Export_PG1316S_DES_17x17.scad]
2025-05-17 Fix PG1316S cap so the cutout is oriented correctly instead of 90 degrees off.
    [PG1316S_DES_17x17.scad]
2025-06-18 Added some PG1316S Chicago Steno models. 17x17 and 18x17 work OK but 19x19 not so much.
    [PG1316S_Chicago_Steno.scad, PG1316S_Chicago_Steno_17x17.scad, PG1316S_Chicago_Steno_18x17.scad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]
2025-06-20 Added several PG CS versions
    [Choc_DES_18x17.scad, PG1316S_Chicago_Steno_17x17.scad, PG1316S_Chicago_Steno_18x17.scad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]
2025-06-20 Add homebar to Choc DES 18x17
    [Choc_DES_18x17.scad]
2025-06-20 Fix homebar resolution
    [Choc_DES_18x17.scad]
2025-06-22 Add new PG1316 cutouts to libraries for foam mods and easier printing. Update DES 18x17 and 19x19 keys to use them, and add versions with extra height for the foam mods.
    [PG1316S_Chicago_Steno_18x17.scad, PG1316S_DES_18x17.scad, PG1316S_DES_18x17_Foam05.scad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]
2025-06-22 Add PG1316 foam mods for 17x17 DES.
    [PG1316S_DES_17x17.scad, PG1316S_DES_17x17_Foam05.scad, PG1316S_DES_17x17_Foam1.scad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]
2025-06-25 Add remaining PG1316 CS types, clean up comments, change filenames from PG1316S to PG1316 since the S is a spring weight and the cutout works for both.
    [PG1316_Chicago_Steno_17x17_Foam05.scad, PG1316_Chicago_Steno_17x17_Foam1.scad, PG1316_Chicago_Steno_17x17_minZ.scad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]
2026-06-21 Add homebrew Subliminal Contradidiction. Cleanup.
    [Subliminal_Contradiction.scad, Subliminal_Contradiction_16x16.scad, Subliminal_Contradiction_17x17.scad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]
2026-06-21 Fix breakage from dumbassery.
    [Subliminal_Contradiction.scad, Subliminal_Contradiction_17x17.scad, Subliminal_Contradiction_17x17_Foam05.scad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]
2026-06-21 Iterate on SC geometry.
    [Subliminal_Contradiction.scad, Subliminal_Contradiction_16x16.scad, Subliminal_Contradiction_17x17.scad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]
2026-06-22 More comparison/iteration on SC.
    [Subliminal_Contradiction.scad, Subliminal_Contradiction_16x16.scad, Subliminal_Contradiction_17x17.scad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]
